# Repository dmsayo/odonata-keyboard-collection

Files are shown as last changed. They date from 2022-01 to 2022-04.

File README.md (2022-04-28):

# The Odonata Keyboard Collection

The Odonata design is an ergonomic 4x12, 48 key keyboard powered by QMK in both split and un-split configurations.

## The Lineup
- The Odonata - The original unibody design using Cherry MX switches
- The Odonata-Split - The split variant using Cherry MX switches

## Tools and Services Used
- KiCad for PCB design
- Fusion360 for plate and case design
- JLCPCB for PCB prototyping
- Ponoko for acrylic laser cutting

## Wonderful Resources Used
- [QMK Documentation](https://docs.qmk.fm/#/)
- [Vial QMK Configurator](https://get.vial.today/)
- PCB design articles:
    - [Masterzen's keyboard pcb design blog](https://www.masterzen.fr/2020/05/03/designing-a-keyboard-part-1/) 
    - [ai03's keyboard pcb design tutorial](https://wiki.ai03.com/books/pcb-design/page/pcb-guide-part-1---preparations)

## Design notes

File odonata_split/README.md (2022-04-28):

# The Odonata_Split Keyboard

The Odonata_split is an ergonomic 4x6 (x2), 48 key split ergonomic keyboard powered by QMK with Vial support.

## Rationale
Evolving from the original Odonata keyboard, this split variant takes the comfortable yet practical format of the original and allows for a wider range of motion to accomodate for a more ergonomic experience.

## Features

- [x] Allows for socketable Arduino Pro Micros, expanding this keyboards features to include wireless communication, USB-C, etc.
- [x] Fully Programmable using QMK
- [x] Vial supported
- [x] Hotswappable switches with Kailh hotswap sockets
- [x] Compact due to its stacked FR4 sandwich design
- [x] Split halves allow for on-the-fly adjustment for a more ergonomic and comfortable typing experience

## Parts List
- TBD

## Building
- TBD

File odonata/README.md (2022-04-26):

# The Odonata Keyboard

The Odonata is an ergonomic 4x12, 48 key unibody ergonomic keyboard powered by QMK with Vial support

## Rationale
Having experience typing on both a Planck and a Redox, this keyboard aims to combine the best features of both: the compact size of the Planck and the comfortable thumb cluster of the Redox.

## Features

- [x] USB-C
- [x] Fully Programmable using QMK
- [x] Stacked Acrylic Keyboard Case
- [x] Vial Support

## Parts List
- TBD

## Building
- TBD

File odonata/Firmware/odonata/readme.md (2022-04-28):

# odonata keyboard firmware

The Odonata is an ergonomic 4x12, 48 key unibody ergonomic keyboard powered by QMK with Vial support.

## Compiling and Flashing

Make example for this keyboard (after setting up your build environment, I prefer QMK MSYS CLI):

    qmk compile -kb odonata -km default

Flashing example for this keyboard:

    qmk flash -kb odonata -km default
    // or use QMK toolbox with auto-flash and press reset button

See the [build environment setup for base QMK](https://docs.qmk.fm/#/getting_started_build_tools) or the [build environment setup for Vial QMK](https://get.vial.today/docs/) and the [make instructions](https://docs.qmk.fm/#/getting_started_make_guide) for more information. Brand new to QMK? Start with our [Complete Newbs Guide](https://docs.qmk.fm/#/newbs).

## Bootloader

Enter the bootloader in 2 ways:

* **Physical reset button (preferred)**: Briefly press the button on the back of the PCB
* **Keycode in layout**: Press the key mapped to `RESET` if it is available - default is hold fn key and tap top left key

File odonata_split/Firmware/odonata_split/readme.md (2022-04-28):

# odonata_split keyboard firmware

The Odonata-Split is an ergonomic 4x6 (x2), 48 key split ergonomic keyboard powered by QMK with Vial support.

## Compiling and Flashing

Make example for this keyboard (after setting up your build environment, I prefer QMK MSYS CLI):

    qmk compile -kb odonata_split -km default

Flashing example for this keyboard:

    qmk flash -kb odonata_split -km default
    // or use QMK toolbox with auto-flash and press reset button

Note: When first flashing boards, please flash both separately and test whether they work properly when plugged in together. Afterward, if you update keymaps you only need to flash the master side.

See the [build environment setup for base QMK](https://docs.qmk.fm/#/getting_started_build_tools) or the [build environment setup for Vial QMK](https://get.vial.today/docs/) and the [make instructions](https://docs.qmk.fm/#/getting_started_make_guide) for more information. Brand new to QMK? Start with our [Complete Newbs Guide](https://docs.qmk.fm/#/newbs).

## Bootloader

Enter the bootloader in 2 ways:

* **Physical reset button (preferred)**: Briefly press the button under the pro micro on the plugged in side
* **Keycode in layout**: Press the key mapped to `RESET` if it is available - default is hold fn key and tap top left key

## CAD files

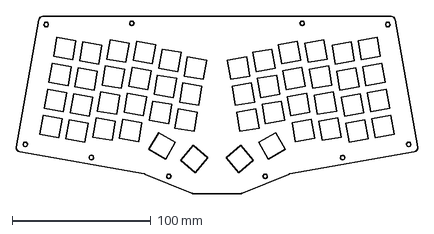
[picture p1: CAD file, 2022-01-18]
odonata/Case_DXF/Top Plate (Low Profile).dxf
290.1 x 127.8 mm

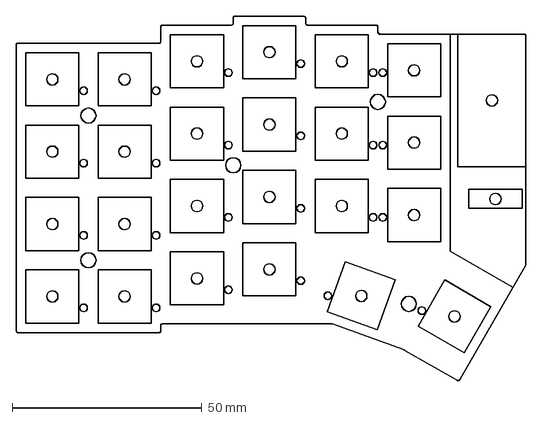
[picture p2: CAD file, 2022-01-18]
odonata_split/Case_DXF/PCB_Placement.dxf
134.2 x 96.1 mm

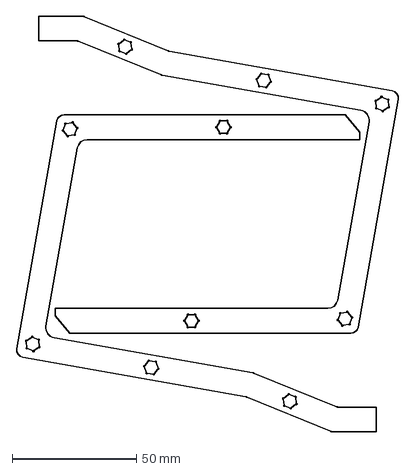
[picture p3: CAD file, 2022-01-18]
odonata/Case_DXF/Middle Plate (Split).dxf
154.2 x 167.6 mm

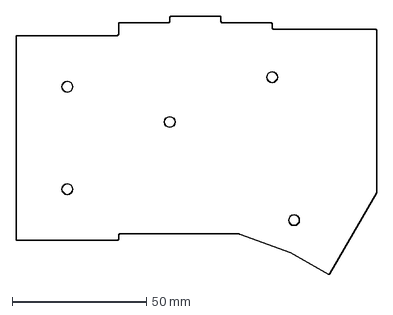
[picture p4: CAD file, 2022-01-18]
odonata_split/Case_DXF/Bottom_Plate.dxf
134.2 x 96.1 mm

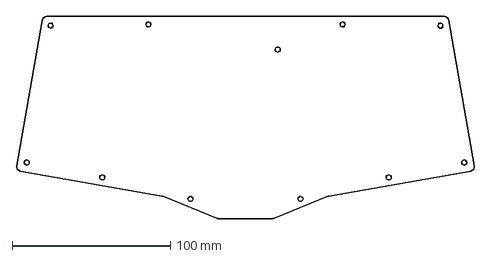
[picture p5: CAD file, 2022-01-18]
odonata/Case_DXF/Bottom Plate.dxf
290.1 x 127.8 mm

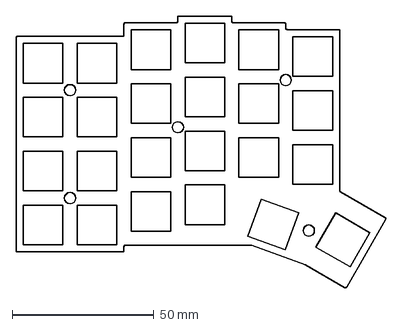
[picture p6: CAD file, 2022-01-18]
odonata_split/Case_DXF/Top_Plate.dxf
130.6 x 96.1 mm

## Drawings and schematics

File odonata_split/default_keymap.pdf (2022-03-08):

## Keyboard planck/rev6

## Layout LAYOUT_ortho_4x12

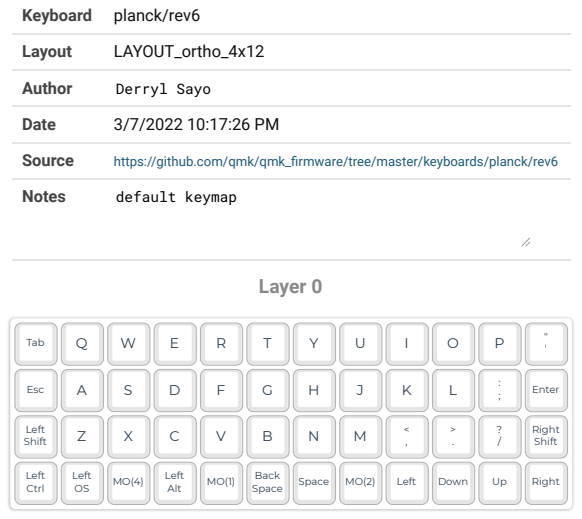
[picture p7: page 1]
Author; Derryl Sayo; Date; Source; https://github.com/qmk/qmk_firmware/tree/master/keyboards/planck/rev6; Notes; Layer 0; default keymap

Tab | Q | W | E | R | T | Y | U | I | O | P | " '

Esc | A | S | D | F | G | H | J | K | L | : ; | Enter

Left Shift | Z | X | C | V | B | N | M | < , | > . | ? / | Right Shift

Left Ctrl | Left OS | MO(4) | Left Alt | MO(1) | Back Space | Space | MO(2) | Left | Down | Up | Right

# Layer 1

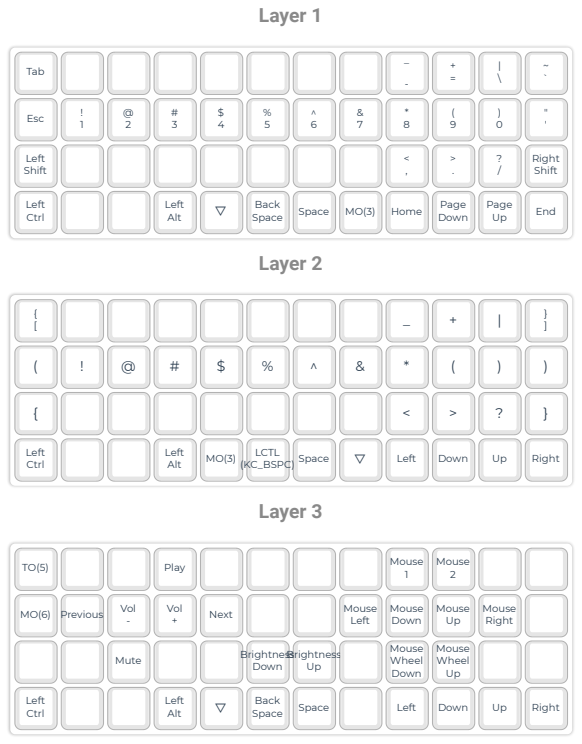
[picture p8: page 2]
Layer 2; Layer 3; Tab; Esc; Left Ctrl; Left; Alt; LCTL (KC_BSPC); Space; Down; Right; Play; Mouse 1; Mouse 2; Previous; Vol -; Vol +; Next; Mouse; Mouse Down; Mouse Up; Mouse Right

Left Shift | | | | | | < , | > . | ? / | Right Shift

Left Ctrl | Left Alt | ▽ | Back Space | Space | MO(3) | Home | Page Down | Page Up | End

Mute | Brightness Down | Brightness Up | | Mouse Wheel Down | Mouse Wheel Up

Left Ctrl | Left Alt | ▽ | Back Space | Space | | Left | Down | Up | Right

# Layer 4

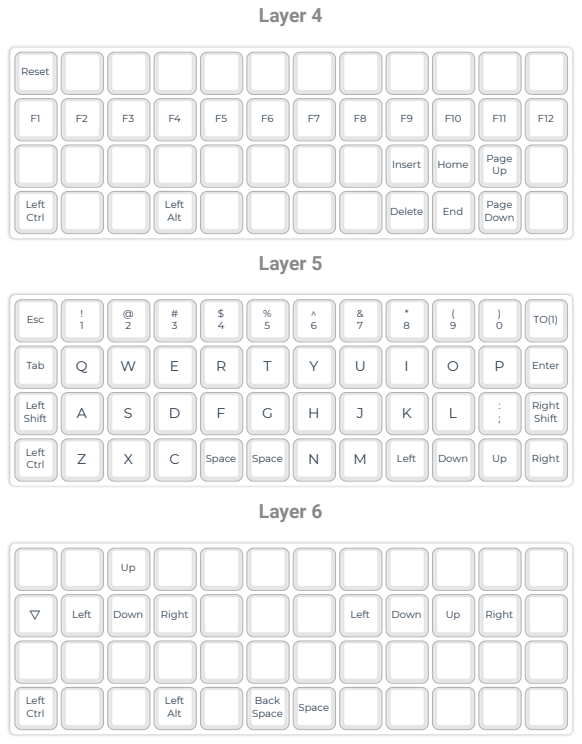
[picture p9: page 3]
Layer 5; Layer 6; Reset; Esc; Tab; Enter; Left; Shift; Right Shift; Ctrl; Space; Down; Right; Left Ctrl; Left Alt; Back Space

Insert | Home | Page Up

Left Ctrl | | | Left Alt | Delete | End | Page Down

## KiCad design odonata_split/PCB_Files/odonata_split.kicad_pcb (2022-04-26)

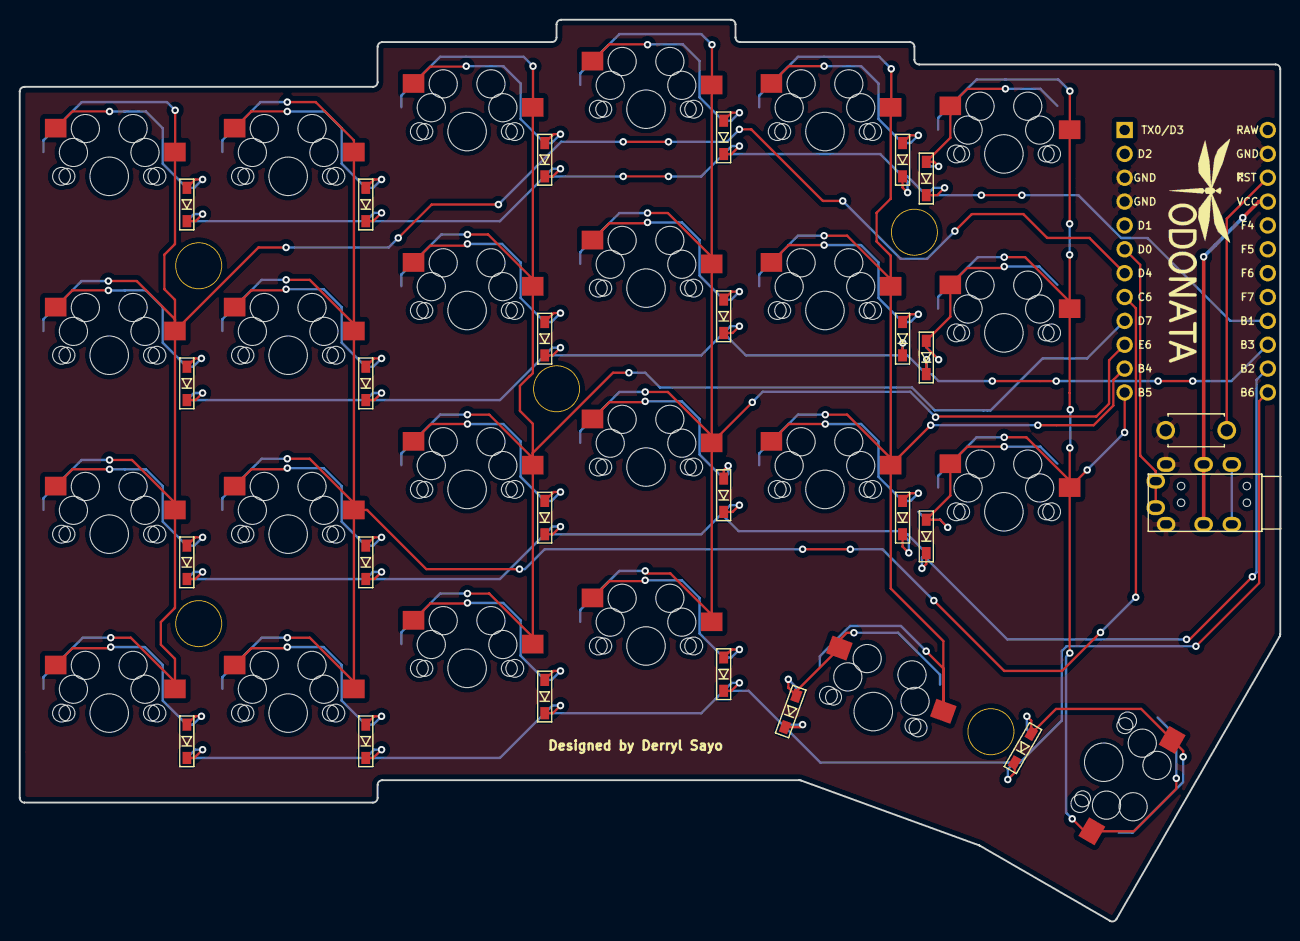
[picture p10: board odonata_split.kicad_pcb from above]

Board: 2 copper layers, 134.2 x 96.0 mm, 51 parts (0 on the bottom side), 38 nets.

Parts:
D1, D2, D3, D4, D5, D6, D7, D8, D9, D10, D11, D12, D13, D14, D15, D16, D17, D18, D19, D20, D21, D22, D23, D24: D_Small; D3_SMD
J1: trrs_num; TRRS-PJ-320A
K1, K2, K3, K4, K5, K6, K7, K8, K9, K10, K11, K12, K13, K14, K15, K16, K17, K18, K19, K20, K21, K22, K23, K24: KEYSW; CherryMX_MidHeight_Hotswap
SW1: Reset; ResetSW
U1: ProMicro; ArduinoProMicro

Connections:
Col0: K1.1, K7.1, K13.1, K19.1, U1.7
Col1: K2.1, K8.1, K14.1, K20.1, U1.8
Col2: K3.1, K9.1, K15.1, K21.1, U1.9
Col3: K4.1, K10.1, K16.1, K22.1, U1.10
Col4: K5.1, K11.1, K17.1, K23.1, U1.11
Col5: K6.1, K12.1, K18.1, K24.1, U1.12
GND: J1.2, SW1.2, U1.3, U1.4, U1.23
unnamed: D1.2, K1.2
unnamed: D2.2, K2.2
unnamed: D3.2, K3.2
unnamed: D4.2, K4.2
unnamed: D5.2, K5.2
unnamed: D6.2, K6.2
unnamed: D7.2, K7.2
unnamed: D8.2, K8.2
unnamed: D9.2, K9.2
unnamed: D10.2, K10.2
unnamed: D11.2, K11.2
unnamed: D12.2, K12.2
unnamed: D13.2, K13.2
unnamed: D14.2, K14.2
unnamed: D15.2, K15.2
unnamed: D16.2, K16.2
unnamed: D17.2, K17.2
unnamed: D18.2, K18.2
unnamed: D19.2, K19.2
unnamed: D20.2, K20.2
unnamed: D21.2, K21.2
unnamed: D22.2, K22.2
unnamed: D23.2, K23.2
unnamed: D24.2, K24.2
Reset: SW1.1, U1.22
Row0: D1.1, D2.1, D3.1, D4.1, D5.1, D6.1, U1.16
Row1: D7.1, D8.1, D9.1, D10.1, D11.1, D12.1, U1.15
Row2: D13.1, D14.1, D15.1, D16.1, D17.1, D18.1, U1.14
Row3: D19.1, D20.1, D21.1, D22.1, D23.1, D24.1, U1.13
Serial_Pin: J1.1, U1.6
VCC: J1.3, U1.21

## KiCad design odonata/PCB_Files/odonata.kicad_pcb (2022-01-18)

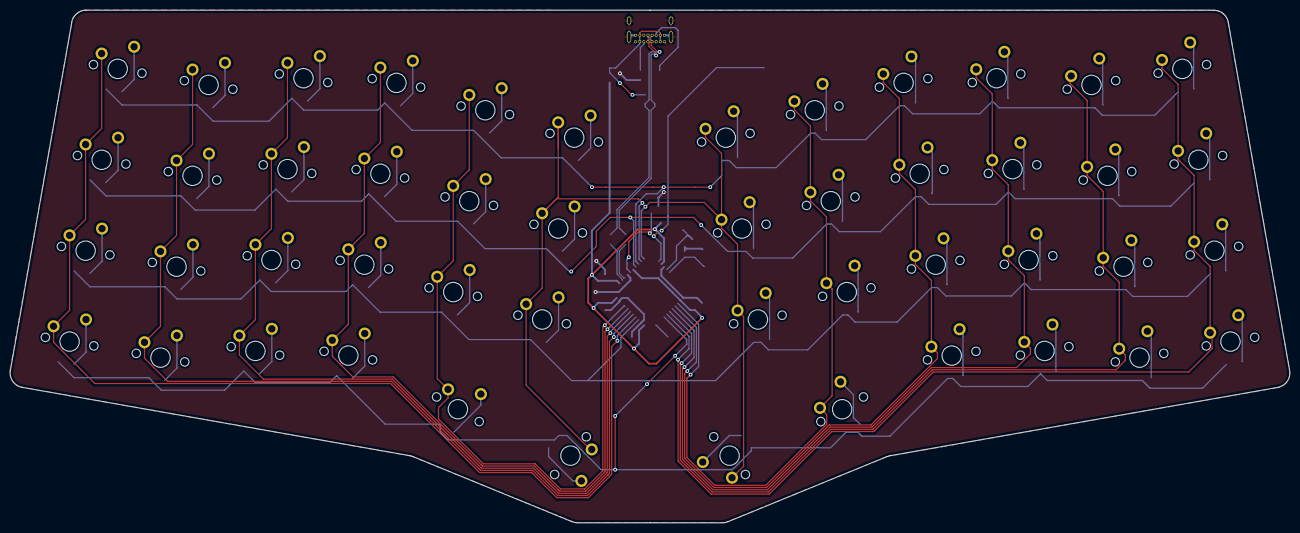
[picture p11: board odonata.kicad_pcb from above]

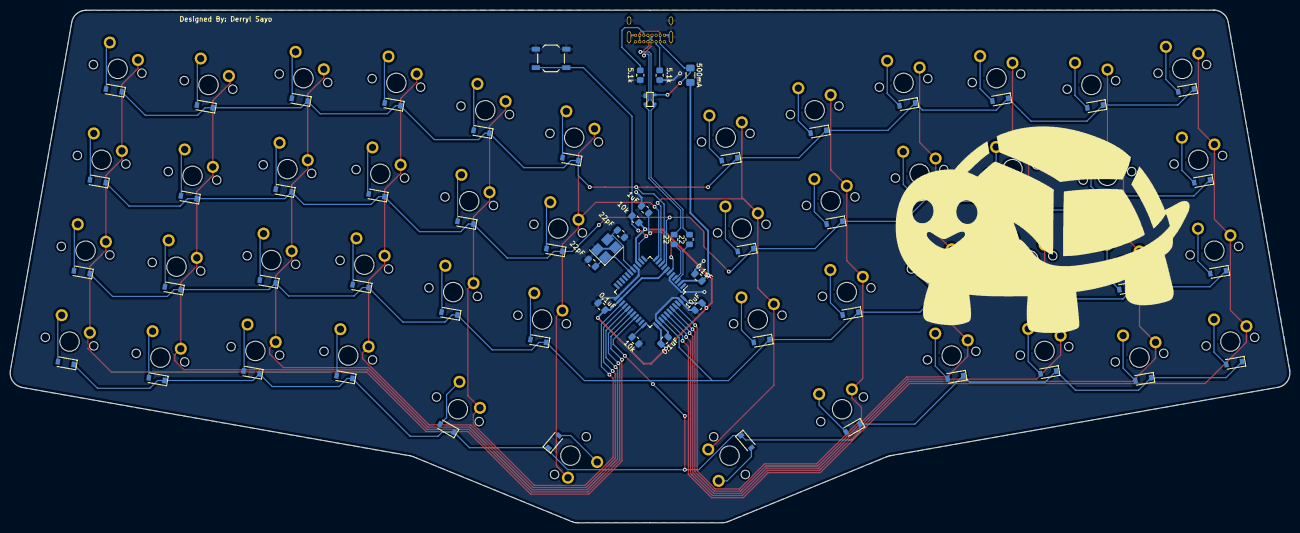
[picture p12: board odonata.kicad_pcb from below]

Board: 2 copper layers, 264.1 x 105.8 mm, 115 parts (67 on the bottom side), 78 nets.

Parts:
C1: 1uF; C_0805_2012Metric_Pad1.18x1.45mm_HandSolder
C2, C3, C4: 0.1uF; C_0805_2012Metric_Pad1.18x1.45mm_HandSolder
C5: 10uF; C_0805_2012Metric_Pad1.18x1.45mm_HandSolder
C6, C7: 22pF; C_0805_2012Metric_Pad1.18x1.45mm_HandSolder
D1, D2, D3, D4, D5, D6, D7, D8, D9, D10, D11, D12, D13, D14, D15, D16, D17, D18, D19, D20, D21, D22, D23, D24, D25, D26, D27, D28, D29, D30, D31, D32, D33, D34, D35, D36, D37, D38, D39, D40, D41, D42, D43, D44, D45, D46, D47, D48: D; D_SOD-123
D49: PRTR5V0U2X; SOT143B
F1: 500mA; Fuse_1206_3216Metric_Pad1.42x1.75mm_HandSolder
J1: USB_C_Receptacle_USB2.0; USB_C_GCT_USB4085
K1, K2, K3, K4, K5, K6, K7, K8, K9, K10, K11, K12, K13, K14, K15, K16, K17, K18, K19, K20, K21, K22, K23, K24, K25, K26, K27, K28, K29, K30, K31, K32, K33, K34, K35, K36, K37, K38, K39, K40, K45, K46, K47, K48: KEYSW; SW_Cherry_MX_PCB_1.00u
K41, K44: KEYSW; SW_Cherry_MX_PCB_1.25u
K42, K43: KEYSW; SW_Cherry_MX_PCB_1.50u
R1, R4: 10k; R_0805_2012Metric_Pad1.20x1.40mm_HandSolder
R2, R3: 22; R_0805_2012Metric_Pad1.20x1.40mm_HandSolder
R5, R6: 5.1k; R_0805_2012Metric_Pad1.20x1.40mm_HandSolder
SW1: SW_PUSH; SW_SPST_TL3342
U1: ATmega32U4-AU; TQFP-44_10x10mm_P0.8mm
Y1: 16MHz; Crystal_SMD_3225-4Pin_3.2x2.5mm_HandSoldering

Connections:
+5V: C2.1, C3.1, C4.1, C5.1, F1.1, R4.1, U1.2, U1.7, U1.14, U1.24, U1.34, U1.44
D+: R3.2, U1.4
D-: R2.2, U1.3
DN: D49.3, J1.A7, J1.B7, R2.1
DP: D49.2, J1.A6, J1.B6, R3.1
GND: C1.2, C2.2, C3.2, C4.2, C5.2, C6.1, C7.2, D49.1, J1.A1, J1.A12, J1.B1, J1.B12, J1.S1, R1.2, R5.2, R6.2, SW1.1, U1.5, U1.15, U1.23, U1.35, U1.43, Y1.2, Y1.4
unnamed: C1.1, U1.6
unnamed: C6.2, U1.17, Y1.1
unnamed: C7.1, U1.16, Y1.3
unnamed: D1.2, K1.2
unnamed: D2.2, K2.2
unnamed: D3.2, K3.2
unnamed: D4.2, K4.2
unnamed: D5.2, K5.2
unnamed: D6.2, K6.2
unnamed: D7.2, K7.2
unnamed: D8.2, K8.2
unnamed: D9.2, K9.2
unnamed: D10.2, K10.2
unnamed: D11.2, K11.2
unnamed: D12.2, K12.2
unnamed: D13.2, K13.2
unnamed: D14.2, K14.2
unnamed: D15.2, K15.2
unnamed: D16.2, K16.2
unnamed: D17.2, K17.2
unnamed: D18.2, K18.2
unnamed: D19.2, K19.2
unnamed: D20.2, K20.2
unnamed: D21.2, K21.2
unnamed: D22.2, K22.2
unnamed: D23.2, K23.2
unnamed: D24.2, K24.2
unnamed: D25.2, K25.2
unnamed: D26.2, K26.2
unnamed: D27.2, K27.2
unnamed: D28.2, K28.2
unnamed: D29.2, K29.2
unnamed: D30.2, K30.2
unnamed: D31.2, K31.2
unnamed: D32.2, K32.2
unnamed: D33.2, K33.2
unnamed: D34.2, K34.2
unnamed: D35.2, K35.2
unnamed: D36.2, K36.2
unnamed: D37.2, K37.2
unnamed: D38.2, K38.2
unnamed: D39.2, K39.2
unnamed: D40.2, K40.2
unnamed: D41.2, K41.2
unnamed: D42.2, K42.2
unnamed: D43.2, K43.2
unnamed: D44.2, K44.2
unnamed: D45.2, K45.2
unnamed: D46.2, K46.2
unnamed: D47.2, K47.2
unnamed: D48.2, K48.2
unnamed: J1.A5, R6.1
unnamed: J1.B5, R5.1
unnamed: R1.1, U1.33
unnamed: R4.2, SW1.2, U1.13
VCC: D49.4, F1.2, J1.A4, J1.A9, J1.B4, J1.B9
col0: K1.1, K13.1, K25.1, K37.1, U1.37
col1: K2.1, K14.1, K26.1, K38.1, U1.38
col2: K3.1, K15.1, K27.1, K39.1, U1.39
col3: K4.1, K16.1, K28.1, K40.1, U1.40
col4: K5.1, K17.1, K29.1, K41.1, U1.41
col5: K6.1, K18.1, K30.1, K42.1, U1.10
col6: K7.1, K19.1, K31.1, K43.1, U1.11
col7: K8.1, K20.1, K32.1, K44.1, U1.25
col8: K9.1, K21.1, K33.1, K45.1, U1.26
col9: K10.1, K22.1, K34.1, K46.1, U1.27
col10: K11.1, K23.1, K35.1, K47.1, U1.28
col11: K12.1, K24.1, K36.1, K48.1, U1.29
row0: D1.1, D2.1, D3.1, D4.1, D5.1, D6.1, D7.1, D8.1, D9.1, D10.1, D11.1, D12.1, U1.9
row1: D13.1, D14.1, D15.1, D16.1, D17.1, D18.1, D19.1, D20.1, D21.1, D22.1, D23.1, D24.1, U1.8
row2: D25.1, D26.1, D27.1, D28.1, D29.1, D30.1, D31.1, D32.1, D33.1, D34.1, D35.1, D36.1, U1.36
row3: D37.1, D38.1, D39.1, D40.1, D41.1, D42.1, D43.1, D44.1, D45.1, D46.1, D47.1, D48.1, U1.30

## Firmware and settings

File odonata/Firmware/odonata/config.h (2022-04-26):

/*
Copyright 2021 Derryl Sayo

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
You should have received a copy of the GNU General Public License
along with this program.  If not, see <http://www.gnu.org/licenses/>.
*/

#pragma once

#include "config_common.h"

/* USB Device descriptor parameter */
#define VENDOR_ID    0xFEED
#define PRODUCT_ID   0x0000
#define DEVICE_VER   0x0001
#define MANUFACTURER Derryl Sayo
#define PRODUCT      odonata

/* key matrix size */
#define MATRIX_ROWS 4
#define MATRIX_COLS 12

/*
 * Keyboard Matrix Assignments
 *
 * Change this to how you wired your keyboard
 * COLS: AVR pins used for columns, left to right
 * ROWS: AVR pins used for rows, top to bottom
 * DIODE_DIRECTION: COL2ROW = COL = Anode (+), ROW = Cathode (-, marked on diode)
 *                  ROW2COL = ROW = Anode (+), COL = Cathode (-, marked on diode)
 *
 */
#define MATRIX_ROW_PINS { B1, B0, F7, B6 }
#define MATRIX_COL_PINS { F6, F5, F4, F1, F0, B2, B3, D4, D6, D7, B4, B5 }
#define UNUSED_PINS

/* NKRO */
#define FORCE_NKRO

/* COL2ROW, ROW2COL */
#define DIODE_DIRECTION COL2ROW

/* Mouse Keys */
#define MOUSEKEY_INTERVAL 16
#define MOUSEKEY_DELAY 0
#define MOUSEKEY_WHEEL_DELAY 0
#define MOUSEKEY_MAX_SPEED 6
#define MOUSEKEY_TIME_TO_MAX 64

//#define LED_NUM_LOCK_PIN B0
//#define LED_CAPS_LOCK_PIN B1
//#define LED_SCROLL_LOCK_PIN B2
//#define LED_COMPOSE_PIN B3
//#define LED_KANA_PIN B4

//#define BACKLIGHT_PIN B7
//#define BACKLIGHT_LEVELS 3
//#define BACKLIGHT_BREATHING

//#define RGB_DI_PIN E2
//#ifdef RGB_DI_PIN
//#    define RGBLED_NUM 16
//#    define RGBLIGHT_HUE_STEP 8
//#    define RGBLIGHT_SAT_STEP 8
//#    define RGBLIGHT_VAL_STEP 8
//#    define RGBLIGHT_LIMIT_VAL 255 /* The maximum brightness level */
//#    define RGBLIGHT_SLEEP  /* If defined, the RGB lighting will be switched off when the host goes to sleep */
/*== all animations enable ==*/
//#    define RGBLIGHT_ANIMATIONS
/*== or choose animations ==*/
//#    define RGBLIGHT_EFFECT_BREATHING
//#    define RGBLIGHT_EFFECT_RAINBOW_MOOD
//#    define RGBLIGHT_EFFECT_RAINBOW_SWIRL
//#    define RGBLIGHT_EFFECT_SNAKE
//#    define RGBLIGHT_EFFECT_KNIGHT
//#    define RGBLIGHT_EFFECT_CHRISTMAS
//#    define RGBLIGHT_EFFECT_STATIC_GRADIENT
//#    define RGBLIGHT_EFFECT_RGB_TEST
//#    define RGBLIGHT_EFFECT_ALTERNATING
/*== customize breathing effect ==*/
/*==== (DEFAULT) use fixed table instead of exp() and sin() ====*/
//#    define RGBLIGHT_BREATHE_TABLE_SIZE 256      // 256(default) or 128 or 64
/*==== use exp() and sin() ====*/
//#    define RGBLIGHT_EFFECT_BREATHE_CENTER 1.85  // 1 to 2.7
//#    define RGBLIGHT_EFFECT_BREATHE_MAX    255   // 0 to 255
//#endif

/* Debounce reduces chatter (unintended double-presses) - set 0 if debouncing is not needed */
#define DEBOUNCE 5

/* define if matrix has ghost (lacks anti-ghosting diodes) */
//#define MATRIX_HAS_GHOST

/* Mechanical locking support. Use KC_LCAP, KC_LNUM or KC_LSCR instead in keymap */
#define LOCKING_SUPPORT_ENABLE
/* Locking resynchronize hack */
#define LOCKING_RESYNC_ENABLE

/* If defined, GRAVE_ESC will always act as ESC when CTRL is held.
 * This is useful for the Windows task manager shortcut (ctrl+shift+esc).
 */
//#define GRAVE_ESC_CTRL_OVERRIDE

/*
 * Force NKRO
 *
 * Force NKRO (nKey Rollover) to be enabled by default, regardless of the saved
 * state in the bootmagic EEPROM settings. (Note that NKRO must be enabled in the
 * makefile for this to work.)
 *
 * If forced on, NKRO can be disabled via magic key (default = LShift+RShift+N)
 * until the next keyboard reset.
 *
 * NKRO may prevent your keystrokes from being detected in the BIOS, but it is
 * fully operational during normal computer usage.
 *
 * For a less heavy-handed approach, enable NKRO via magic key (LShift+RShift+N)
 * or via bootmagic (hold SPACE+N while plugging in the keyboard). Once set by
 * bootmagic, NKRO mode will always be enabled until it is toggled again during a
 * power-up.
 *
 */
//#define FORCE_NKRO

/*
 * Feature disable options
 *  These options are also useful to firmware size reduction.
 */

/* disable debug print */
//#define NO_DEBUG

/* disable print */
//#define NO_PRINT

/* disable action features */
//#define NO_ACTION_LAYER
//#define NO_ACTION_TAPPING
//#define NO_ACTION_ONESHOT

/* disable these deprecated features by default */
#define NO_ACTION_MACRO
#define NO_ACTION_FUNCTION

/* Bootmagic Lite key configuration */
//#define BOOTMAGIC_LITE_ROW 0
//#define BOOTMAGIC_LITE_COLUMN 0

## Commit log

2022-01-18 refactored file structure
    [Bottom Plate.dxf, Bottom-Plate.kicad_pcb, Bottom-Plate.sch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]
2022-01-18 .gitignore not working
    [rainier48.csv]
2022-04-26 begin naming refactor
    [Bottom Plate.dxf, Bottom-Plate.kicad_pcb, Bottom-Plate.sch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]
2022-04-26 fixed vial unlock combo
    [config.h]
2022-04-28 fixed odonata mouse keys
    [config.h]

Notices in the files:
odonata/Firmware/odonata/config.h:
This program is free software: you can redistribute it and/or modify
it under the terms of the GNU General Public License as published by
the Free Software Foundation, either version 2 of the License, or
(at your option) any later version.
